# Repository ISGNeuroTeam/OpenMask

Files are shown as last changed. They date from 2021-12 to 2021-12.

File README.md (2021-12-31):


#


Наша команда разрабатывает open hardware open software проект уже более года.

### OpenMask= Умная маска + аналитическая Платформа + экспертиза моделей

**Описание проекта:** умная маска с 14 различными типами датчиков собирает биомедицинские данные с человека. Фиксирует и анализирует показатели работы сердечно-сосудистой, дыхательной и вегетативной нервной системы, а также данные о состоянии окружающей среды и типе физической активности в конкретный момент времени. Данные загружаются в открытую аналитическую Платформу, на их основе определяются потенциальные возможности организма и оценивается эффективность и безопасность тренировок.

**Цель проекта:**  создать бесплатную и открытую для самостоятельного повторения энтузиастами и стартапами IIoT  платформу, позволяющую собирать в открытую ОТ.Платформу  биомедицинские данные с активно действующего человека.

Эта инициатива позволяет нашему сообществу накапливать данные о работе человеческого организма в самых разных ситуациях и условиях, строить модели ML и сервисы решающие реальные проблемы людей.

**Все компоненты проекта полностью открыты и доступны для самостоятельных повторения и модификации**
**По ссылке на Github найдешь:**
+ Модели масок для 3D печати
+ Список необходимой электроники 
+ Инструкции по сборке 
+ Исходный код прошивки контроллера
+ Описание протокола взаимодействия с Аналитической платформой
+ Приложение для Android

**Придумай свой проект на основе OpenMask**
+ Сформулируй интересующую тебя актуальную проблему в области повышения качества жизни
+ Вместе с командой придумайте эксперимент
+ Соберите маску
+ Соберите данные с помощью маски и постройте модели
+ Или используйте загруженные в платформу данные для моделей
+ Сделайте стартап на основе ОТ.Платформы и маски

Конструкция устройства, и всё программное обеспечение полностью открыто и позволяет строить свои фитнес-гаджеты на его основе.

### Структура файлов проекта
> 1. 3D модели - файлы 3D моделей
> > 1. Главная часть (корпус) 
> > > 1. Главная часть - без отверстий
> > > 2. Главная часть - с отверстиями
> > 2. Крышки фильтров
> > > 1. Крышки - вид 1
> > > 2. Крышки - вид 2
> > > 3. Крышки - вид 3
> > 3. Кнопка
> > > 1. Кнопка без защелки
> > > 2. Кнопка с защелкой
> > 4. Датчик ФПГ
> > 6. Датчик внутренней среды
> 2. neuromask_esp8266 - исходники прошивки контроллера esp8266
> > 1. neuroMask_esp8266 - прошика контроллера без ШИЛДА
> > 2. neuroMask_esp8266_chield - прошика контроллера с ШИЛДОМ
> 3. Mobile App TrainerII - файл установки мобильного приложения ТренерИИ

### Вступление в Wellness Data Club — максимально короткий путь реализации твоих идей, МЕНЯЮЩИХ МИР К ЛУЧШЕМУ
[https://welldata.club](https://welldata.club)

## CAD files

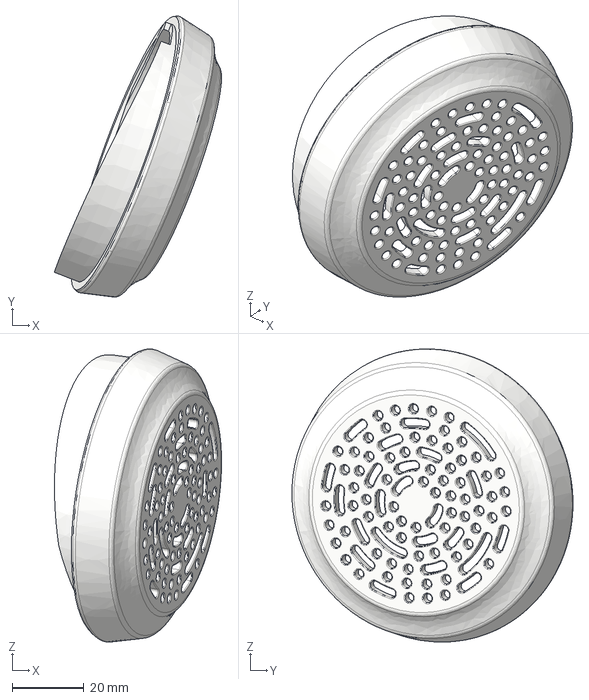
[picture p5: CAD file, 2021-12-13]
1. 3D модели/2. Крышки фильтров/1. Крышки - вид 1/крышка 1 левая.step
46.5 x 78.2 x 81.5 mm

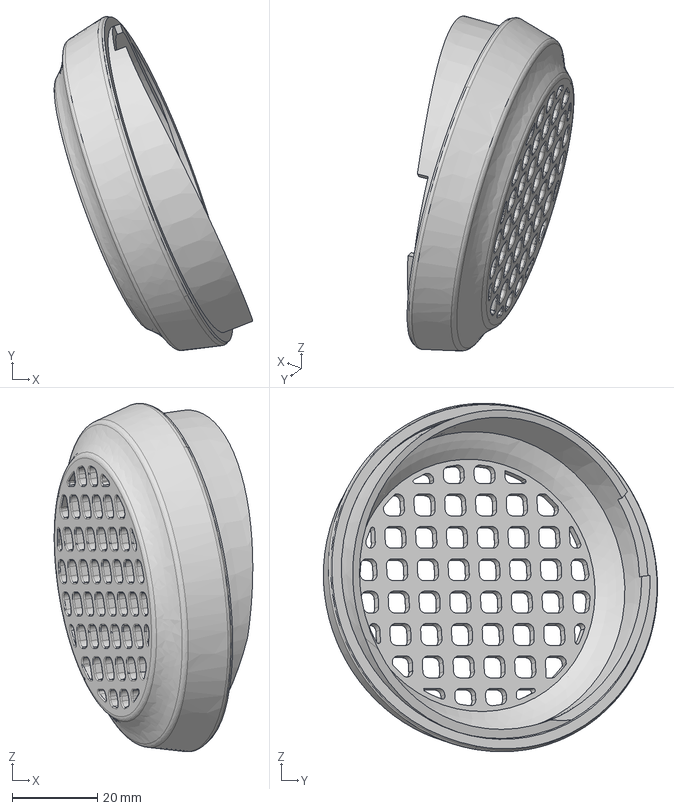
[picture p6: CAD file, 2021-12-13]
1. 3D модели/2. Крышки фильтров/3. Крышки - вид 3/крышка 3 правая.step
46.5 x 78.2 x 81.5 mm

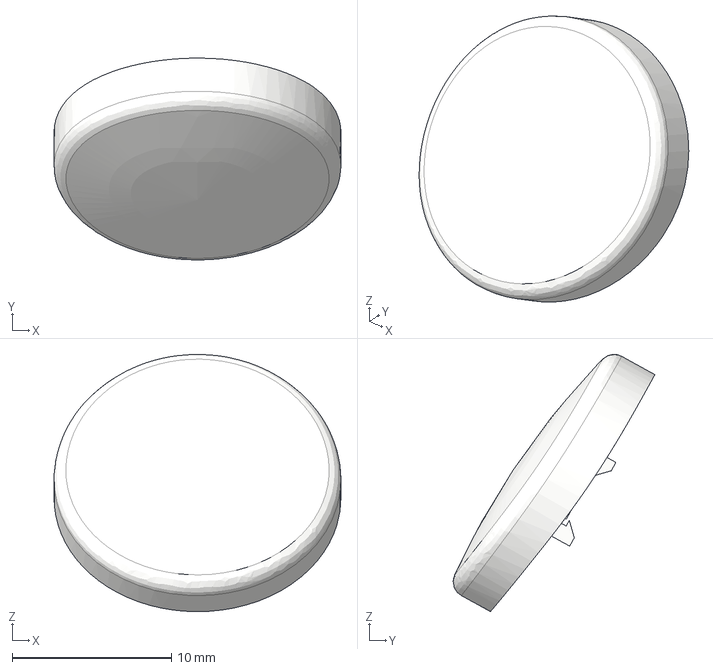
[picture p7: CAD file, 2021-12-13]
1. 3D модели/3. Кнопка/1. Кнопка без защелки/кнопка без защелок.step
18.0 x 12.7 x 16.1 mm

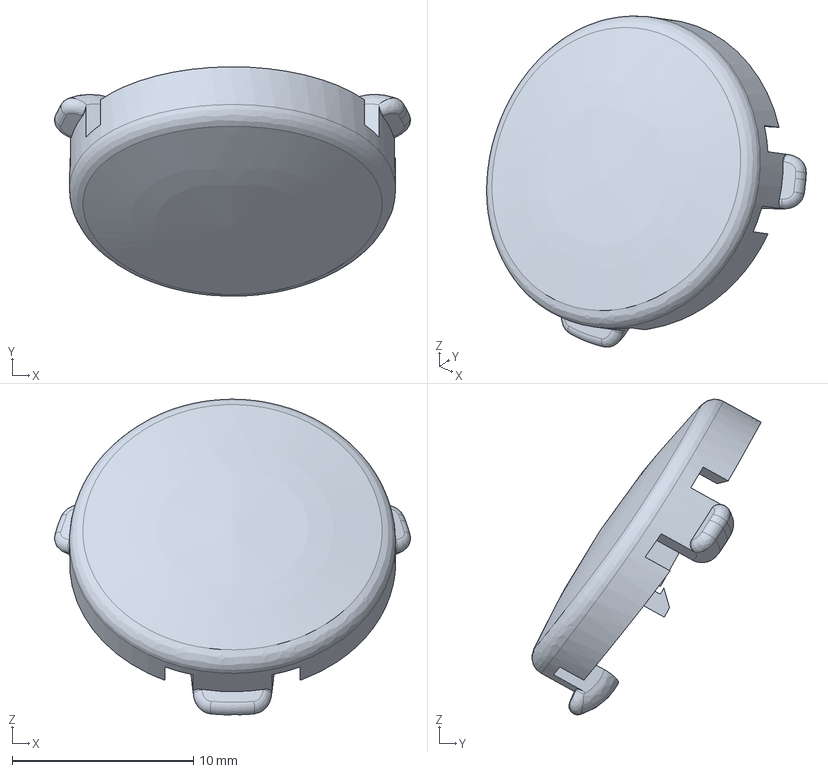
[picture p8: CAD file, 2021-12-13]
1. 3D модели/3. Кнопка/2. Кнопка с защелкой/кнопка с защелками.step
19.6 x 12.7 x 17.4 mm

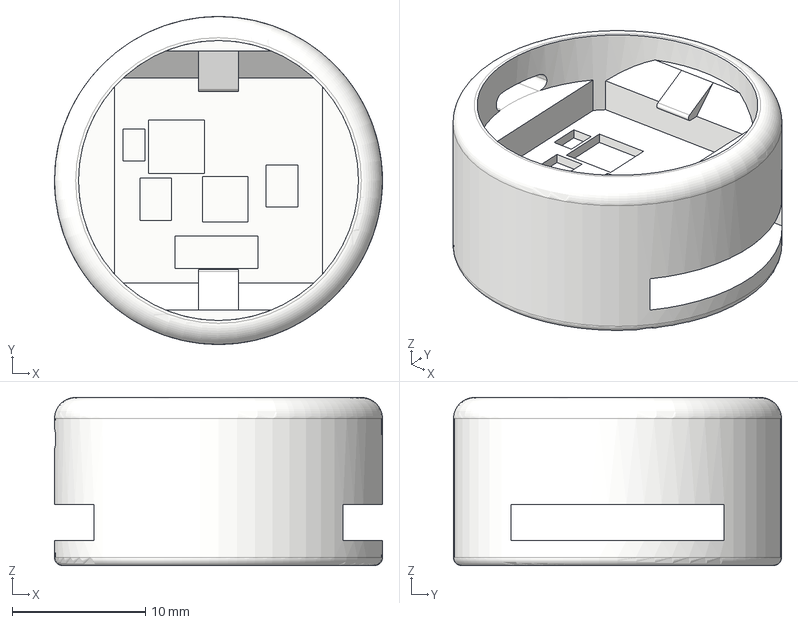
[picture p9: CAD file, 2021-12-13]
1. 3D модели/5. Датчик ФПГ/крепление фпг и иму.step
24.6 x 24.6 x 12.6 mm

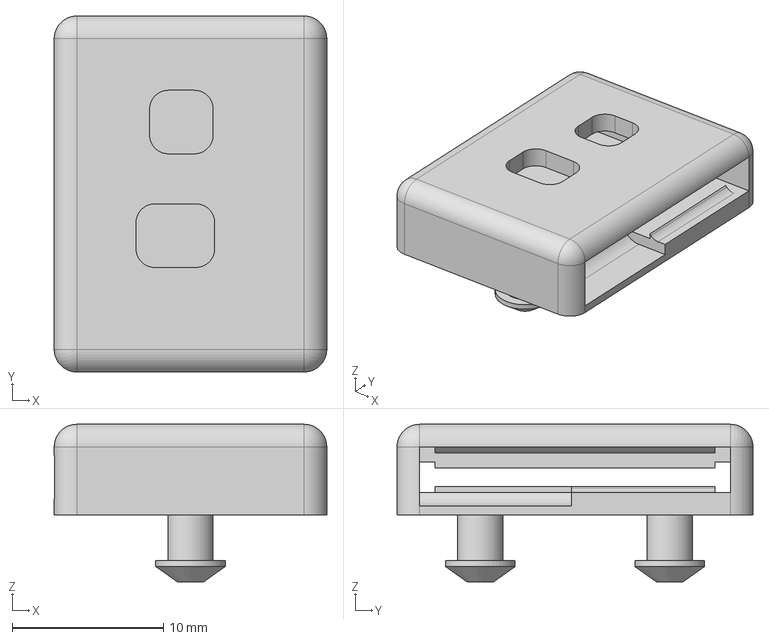
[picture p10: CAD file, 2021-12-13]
1. 3D модели/6. Датчик внутренней среды/крепление датчика внутренней среды.step
18.0 x 23.5 x 10.4 mm

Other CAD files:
1. 3D модели/2. Крышки фильтров/2. Крышки - вид 2/крышка 2 левая.step
1. 3D модели/2. Крышки фильтров/1. Крышки - вид 1/крышка 1 правая.step
1. 3D модели/2. Крышки фильтров/2. Крышки - вид 2/крышка 2 правая.step
1. 3D модели/2. Крышки фильтров/3. Крышки - вид 3/крышка 3 левая.step
1. 3D модели/3. Кнопка/1. Кнопка без защелки/кнопка без защелок.stl
1. 3D модели/3. Кнопка/2. Кнопка с защелкой/кнопка с защелками.stl
1. 3D модели/5. Датчик ФПГ/крепление фпг и иму.stl
1. 3D модели/6. Датчик внутренней среды/крепление датчика внутренней среды.stl

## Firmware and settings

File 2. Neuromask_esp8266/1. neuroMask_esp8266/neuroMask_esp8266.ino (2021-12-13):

#include <Wire.h>
#include <heartRate.h>
#include <MAX30105.h>
#include <Ticker.h>
#include <FaBo9Axis_MPU9250.h>
#include "EEPROM.h"
#include "DFRobot_CCS811.h"
#include "SparkFunBME280.h"
#include "Adafruit_HDC1000.h"
#include <Adafruit_NeoPixel.h>
#include <ESP8266WiFi.h>
#include <WiFiUdp.h>

#include <FIR.h>
FIR<int, 103> fir_lp;
FIR<int, 103> fir_lp_1;

#include <WiFiManager.h> // https://github.com/tzapu/WiFiManager

#define DEBUG false
//#define RESET_EEPROM false // uncomment to clear eeprom

//#define WEMOS

#ifdef WEMOS
#define BUTTONPIN 4
#define POWERPIN  5
#else
#define BUTTONPIN D4
#define POWERPIN  D5
// sensor keys
#endif

bool SLEEPMODE  = false;

// eeprom adress for save port host
#define IP_ADDRESS 0x00
#define PORT_ADDRESS 0x100
#define ASAP_ADDRESS 0x200


//ESP32AnalogRead adc; // adc conversion with calibration
#define VOLTAGE_BAT_PIN  A0
#define VOLTAGE_KOEF (100 + 210)/210  //(R1+R2)/R2
uint8_t BATPERCENTVALUE  = 0;  // save percent batery level

#define LEDS_COUNT  2
#define LEDS_PIN  12

Adafruit_NeoPixel pixels(LEDS_COUNT, LEDS_PIN, NEO_GRB + NEO_KHZ800);

#define CO2 0x10
#define O2 0x11
#define T_BODY 0x12
#define HUM 0x13
#define TVOC 0x14
#define PRESS 0x15
#define T_OUT 0x16
#define CARDIO 0x17
#define AX 0x18
#define AY 0x19
#define AZ 0x1A
#define GX 0x1B
#define GY 0x1C
#define GZ 0x1D
#define MX 0x1E
#define MY 0x1F
#define MZ 0x20
#define SPO2_RED 0x21
#define SPO2_IR 0x22
#define SPO2_GREEN 0x23
#define SPO2 0x24
#define ALT 0x25
#define HR 0x26
#define STEP 0x27
#define BAT_PERCENT 0x28
#define TVOCEXT 0x29
#define CO2EXT 0x2A
#define HUMEXT 0x2B



// received commands keys

#define STARTSENDDATA     0x50
#define STOPSENDDATA      0x51
#define SETFREQENCY       0x52
#define WITHPROCESSING    0x53
#define GETCONFIGSENSORS  0x54
#define GETMACADRESS      0x55





WiFiManager wm;
WiFiManagerParameter custom_address; // global param ( for non blocking w params )
WiFiManagerParameter custom_port; // global param ( for non blocking w params )
WiFiManagerParameter asAP; // global param ( for non blocking w params )


static const uint16_t startOfPacket =  0xAAF0;
static const uint16_t endOfPacket =  0xAAF1;

#define SENSCOUNT 22
#define DEFAULT_FREQ_HZ 100


Ticker sender;

Ticker batreader;

Ticker batShower;


volatile uint8_t sensReadCount = 0;
uint8_t sensorsActive[SENSCOUNT];

MAX30105 particleSensor; // sensor init

FaBo9Axis imu;  // Gyroscop Acellerometr

DFRobot_CCS811 CCS811;  // tvoc co2
DFRobot_CCS811 CCS811EXT(&Wire, 0x5B);  // tvoc co2 external sensor

BME280 bme;
BME280_SensorMeasurements measurements; // presure  & Humidity sens

Adafruit_HDC1000 hdc = Adafruit_HDC1000(); // external & Humidity sens

#define SEALEVELPRESSURE_HPA (1013.25) // Average sea-level pressure from wiki

typedef struct {
  uint8_t sensorId;   // id sensor
  float value;   // value
} structSensor;  // sensor struct

typedef struct {
  uint16_t dataLength;  // length data without start stop bits and self
  uint16_t timeStamp[2]; // timesatmp milliseconds from boot
  structSensor sensors[SENSCOUNT];  // array of sensors struct
} structPacket;  // struct of packet to send client

structPacket packet;

typedef struct {
  char modulName[10];  // name
  void (*functionRead)(void);  // coomand to read data
  bool enable;  // enable or disable reading
} structDevice; // struct of modul with sesors

void imuSensRead();
void practicleRead();
void readSensors();
void TvocCo2Read();
void TvocCo2ReadExt();
void HumiPressRead();
void HumiExtRead();
void VoltageRead();

structDevice devices[] = {  {"Imu", imuSensRead,   true},
  {"SpO2", practicleRead, true},
  {"CO2Tvoc", TvocCo2Read, true},
  {"ExCO2Tvoc", TvocCo2ReadExt, true},
  {"HumiPress", HumiPressRead, true},
  {"HumiExt", HumiExtRead, true},
  {"Voltage", VoltageRead, true}
};

// WiFi network name and password:
//const char * networkName = "";
//const char * networkPswd = "";

//IP address to send UDP data to:
// either use the ip address of the server or
// a network broadcast address

String udpAddress = "10.77.2.36";
int udpPort = 3333;

//Are we currently connected?
boolean connected = false;

//The udp library class
WiFiUDP udp;


float filter(float inputVal) {
  //implement the IIR filter
  //reference: The Scientist and Engineer's Guide to Digital Signal Processing By Steven W. Smith, Ph.D.
  //  http://www.dspguide.com/ch19/2.htm
  //This is a "single pole" filter.

  //x is the decay between adjacent samples. Choose any number between 0 and 1 (except 1).
  const float x = 0.86;
  static float outputVal = 0; //make it static so it's stored for the function to use again the next time it's called

  outputVal = outputVal * x + inputVal * (1 - x);
  return outputVal;
}

void writeStringToEEPROM(int addrOffset, String strToWrite)
{
  byte len = strToWrite.length();
  EEPROM.write(addrOffset, len);
  for (int i = 0; i < len; i++)
  {
    EEPROM.write(addrOffset + 1 + i, strToWrite[i]);
  }
}
String readStringFromEEPROM(int addrOffset)
{
  int newStrLen = EEPROM.read(addrOffset);
  char data[newStrLen + 1];
  for (int i = 0; i < newStrLen; i++)
  {
    data[i] = EEPROM.read(addrOffset + 1 + i);
    //Serial.print(data[i]);
  }
  data[newStrLen] = '\0'; // !!! NOTE !!! Remove the space between the slash "/" and "0" (I've added a space because otherwise there is a display bug)
  return String(data);
}

void disableDeviceByName(char * modulName)
{
  for (int i = 0; i < sizeof(devices) / sizeof(structDevice); i++ )
  {

    if (!memcmp(devices[i].modulName, modulName, strlen(modulName)))
    {
#if DEBUG
      Serial.println("Modul " + String(modulName) + " disable");
#endif
      devices[i].enable = false;
    }
  }
}

void timerSenderStart(int freq) {
#if DEBUG
  Serial.printf("Timer value is: %f\n", float(1) / freq);
#endif
  sender.attach(float(1) / freq, readSensors);
}

void timerSenderStop()
{
  sender.detach();
}

void timerSenderChangeFreq(int freq) // change frequncy timer
{
  timerSenderStop();
  timerSenderStart(freq);
}

void addDataSensToPacket(uint8_t sensorId, float value) // add sensor data to packet
{
  int sensIndex = (packet.dataLength /  (sizeof(uint8_t) + sizeof(float))) % SENSCOUNT;

  packet.sensors[sensIndex].sensorId = sensorId;
  packet.sensors[sensIndex].value = value;
  packet.dataLength += (sizeof(uint8_t) + sizeof(float));

}

void clearPacket()  // clear packet
{

  memset(&packet, 0, sizeof(packet));
}



bool VoltageInit()
{
  //adc.attach(VOLTAGE_BAT_PIN);
  return true;

}


bool practicleSensInit()
{
  // Initialize sensor
  if (particleSensor.begin(Wire, I2C_SPEED_FAST) == false) //Use default I2C port, 400kHz speed
  {
    Serial.println("MAX30105 was not found. Please check wiring/power. ");
    disableDeviceByName("SpO2");
    return false;
  }

  //Setup to sense up to 18 inches, max LED brightness
  byte ledBrightness = 0x2A; //Options: 0=Off to 255=50mA
  byte sampleAverage = 2; //Options: 1, 2, 4, 8, 16, 32
  byte ledMode = 3; //Options: 1 = Red only, 2 = Red + IR, 3 = Red + IR + Green
  int sampleRate = 3200; //Options:SENSCOUNT 50, 100, 200, 400, 800, 1000, 1600, 3200
  int pulseWidth = 69; //Options: 69, 118, 215, 411
  int adcRange = 4096; //Options: 2048, 4096, 8192, 16384

  particleSensor.setup(ledBrightness, sampleAverage, ledMode, sampleRate, pulseWidth, adcRange); //Configure sensor with these settings
  // default value (byte powerLevel = 0x1F, byte sampleAverage = 4, byte ledMode = 3, int sampleRate = 400, int pulseWidth = 411, int adcRange = 4096);
  return true;
}

bool imuSensInit()
{
  if (imu.begin()) {
    return true;
  }
  else {
    Serial.println("Imu was not found. Please check wiring/power.");
    disableDeviceByName("Imu");

    return false;
  }
}

bool TvocCo2Init()
{
  if (CCS811.begin() != 0) {
    Serial.println("failed to init chip, please check if the chip connection is fine");
    disableDeviceByName("CO2Tvoc");
    return false;

  }
  else
  {
    return true;
  }
}

bool TvocCo2InitExt()
{
  if (CCS811EXT.begin() != 0) {
    Serial.println("failed to init ccs811 external chip, please check if the chip connection is fine");
    disableDeviceByName("ExCO2Tvoc");
    return false;
  }
  else
  {
    return true;
  }
}

bool HumiExtSensInit()
{
  if (!hdc.begin()) {
    Serial.println("Couldn't find sensor HDC100x , check wiring!");
    disableDeviceByName("HumiExt");
    return false;
  }
  return true;
}


bool pressureHumiSensInit()
{
  bme.setI2CAddress(0x77);
  if (bme.beginI2C() == false) {
    Serial.println("Could not find a valid BME285 sensor, check wiring!");
    disableDeviceByName("HumiPress");
    return false;
  }
  bme.setStandbyTime(6);
  bme.readAllMeasurements(&measurements);
  //bme.setReferencePressure(101750);
  delay(10);
  return true;
}

void readBatPercent()
{
  float batVoltage = analogRead(A0);

  float max_adc = 730;
  float min_adc = 530;
  //Serial.println(batVoltage);


  //BATPERCENTVALUE = batVoltage;

  if (batVoltage > max_adc)
  {
    BATPERCENTVALUE = 100;
  }
  else if (batVoltage < min_adc)
  {
    BATPERCENTVALUE = 0;
  }
  else
  {
    BATPERCENTVALUE  = map(batVoltage, min_adc, max_adc, 0, 100);
  }

}

void VoltageRead()
{
  static uint32_t lastTimeSend = millis();
  if (millis() - lastTimeSend > 1000) // send each seconds
  {
    addDataSensToPacket(BAT_PERCENT, BATPERCENTVALUE);
    sensReadCount += 1;
    lastTimeSend = millis();
  }

}

void HumiExtRead()
{
  float hum, temp;
  if (hdc.readHumidityAndTemp(&hum, &temp))
  {
    addDataSensToPacket(HUMEXT, hum);
    sensReadCount += 1;
  }


}

void HumiPressRead()
{
  if (!bme.isMeasuring())
  {
    bme.readAllMeasurements(&measurements);

    float alt =  ((float) - 44330.77) * (pow(((float)measurements.pressure / (float)bme.getReferencePressure()), 0.190263) - (float)1);
    Serial.println(measurements.pressure);

    addDataSensToPacket(T_OUT, measurements.temperature);
    addDataSensToPacket(PRESS, measurements.pressure);
    addDataSensToPacket(HUM, measurements.humidity);
    addDataSensToPacket(ALT, alt);
    sensReadCount += 4;
  }


}



void TvocCo2Read() {
  if (CCS811.checkDataReady() == true) {
    float co2 = CCS811.getCO2PPM();
    float ppm = CCS811.getTVOCPPB();
    addDataSensToPacket(TVOC, ppm);
    addDataSensToPacket(CO2, co2);
    sensReadCount += 2;

  } else {


    return;
  }

}

void TvocCo2ReadExt() {

  if (CCS811EXT.checkDataReady() == true) {
    float co2 = CCS811EXT.getCO2PPM();
    float ppm = CCS811EXT.getTVOCPPB();
    addDataSensToPacket(TVOCEXT, ppm);
    addDataSensToPacket(CO2EXT, co2);
    sensReadCount += 2;

  } else {
    return;
  }

}

void imuSensRead()
{
  float ax, ay, az;
  float gx, gy, gz;
  float mx, my, mz;
  float temp;
  sensReadCount += 10;

  imu.readAccelXYZ(&ax, &ay, &az);
  imu.readGyroXYZ(&gx, &gy, &gz);
  imu.readMagnetXYZ(&mx, &my, &mz);
  imu.readTemperature(&temp);
  addDataSensToPacket(AX, ax);
  addDataSensToPacket(AY, ay);
  addDataSensToPacket(AZ, az);
  addDataSensToPacket(GX, gx);
  addDataSensToPacket(GY, gy);
  addDataSensToPacket(GZ, gz);
  addDataSensToPacket(MX, mx);
  addDataSensToPacket(MY, my);
  addDataSensToPacket(MZ, mz);
  addDataSensToPacket(T_BODY, temp);
#if DEBUG
  //Serial.println(ax);
#endif
#if DEBUG
  //Serial.println(gx);
#endif
#if DEBUG
  //Serial.println(temp);
#endif
}



float getBPM(float value)
{
  static long lastBeat = 0; //Time at which the last beat occurred

  if (checkForBeat(value) == true)
  {
    //We sensed a beat!
    long delta = millis() - lastBeat;
    lastBeat = millis();

    float beatsPerMinute = 60 / (delta / 1000.0);

    return filter(beatsPerMinute);

  }
  return -1;
}

void practicleRead() {
  static int counter = 0;
  particleSensor.check();
  if (!particleSensor.available())
  {

#if DEBUG
    Serial.println("no data");
#endif
    return;
  }
  float red, ir, green;

  red = particleSensor.getFIFORed();
  ir = particleSensor.getFIFOIR();
  green = particleSensor.getFIFOGreen();
  sensReadCount += 3;
  particleSensor.nextSample();
  addDataSensToPacket(SPO2_RED, red);
  addDataSensToPacket(SPO2_IR, ir);
  addDataSensToPacket(SPO2_GREEN, green);


  float clean_ir = fir_lp.processReading(ir);
  float clean_red = fir_lp_1.processReading(red);
  if (ir < 50000)
    return;
  float beatsPerMinute = getBPM(clean_ir);

  if (beatsPerMinute > 30 && beatsPerMinute < 220 )
  {

    addDataSensToPacket(HR, beatsPerMinute);
    sensReadCount++;

  }

}
uint8_t activeSensorCounter()
{
  uint8_t counter = 0;

  for (uint8_t i = 0; i < SENSCOUNT; i++)
  {
    if (sensorsActive[i] != 0)
    {
      counter++;
    }
  }
  return counter;
}
uint8_t scanModules()
{
  uint8_t counter = 0; // sensors counter

  if (imuSensInit())
  {
    sensorsActive[counter++] =  AX;
    sensorsActive[counter++] =  AY;
    sensorsActive[counter++] =  AZ;
    sensorsActive[counter++] =  GX;
    sensorsActive[counter++] =  GY;
    sensorsActive[counter++] =  GZ;
    sensorsActive[counter++] =  MX;
    sensorsActive[counter++] =  MY;
    sensorsActive[counter++] =  MZ;
    sensorsActive[counter++] =  T_BODY;
  }
  if (practicleSensInit())
  {
    sensorsActive[counter++] = SPO2_RED;
    sensorsActive[counter++] = SPO2_IR;
    sensorsActive[counter++] = SPO2_GREEN;
  }

  if (TvocCo2Init())
  {
    sensorsActive[counter++] = TVOC;
    sensorsActive[counter++] = CO2;
  }
  if (TvocCo2InitExt())
  {
    sensorsActive[counter++] = TVOCEXT;
    sensorsActive[counter++] = CO2EXT;
  }


  if (pressureHumiSensInit())
  {
    sensorsActive[counter++] = PRESS;
    sensorsActive[counter++] = HUM;
    sensorsActive[counter++] = T_OUT;
    sensorsActive[counter++] = ALT;
  }

  if (HumiExtSensInit())
  {
    sensorsActive[counter++] = HUMEXT;
  }
  if (VoltageInit())
  {
    sensorsActive[counter++] = BAT_PERCENT;
  }

  return counter;
}

String getParam(String name) {
  //read parameter from server, for customhmtl input
  String value;
  if (wm.server->hasArg(name)) {
    value = wm.server->arg(name);
  }
  return value;
}

void saveParamCallback() {

  //#if DEBUG
  Serial.println("[CALLBACK] saveParamCallback fired");
  Serial.println("PARAM hostip = " + getParam("hostip"));
  Serial.println("PARAM hostport = " + getParam("hostport"));
  Serial.println("PARAM asAP = " + getParam("asAP"));
  //#endif

  writeStringToEEPROM(IP_ADDRESS, getParam("hostip"));
  writeStringToEEPROM(PORT_ADDRESS, getParam("hostport"));
  writeStringToEEPROM(ASAP_ADDRESS, getParam("asAP"));
  EEPROM.commit();
}



//wifi event handler
void WiFiEvent(WiFiEvent_t event) {
  switch (event) {
    case WIFI_EVENT_SOFTAPMODE_STACONNECTED:
      {
#if DEBUG
        Serial.print("Client connected! IP address: ???");
#endif
        if (!connected)
          udp.begin(udpPort);
        connected = true;
        //send_sensors();
      }
      break;

    case WIFI_EVENT_STAMODE_GOT_IP:
      {
        //When connected set
#if DEBUG
        Serial.print("WiFi connected! IP address: ");
#endif
#if DEBUG
        Serial.println(WiFi.localIP());
#endif
        //initializes the UDP state
        //This initializes the transfer buffer
        udp.begin(udpPort);
        connected = true;
        send_sensors();
      }
      break;
    case WIFI_EVENT_STAMODE_DISCONNECTED:
      {
#if DEBUG
        Serial.println("WiFi lost connection");
#endif
        connected = false;
        break;
      }
    default: break;
  }
}

void startConfigAPServer()
{
  WiFi.mode(WIFI_STA); // explicitly set mode, esp defaults to STA+AP
  //WiFi.setTxPower(WIFI_POWER_MINUS_1dBm);

  WiFi.onEvent(WiFiEvent); //register event handler

  int customFieldLength = 40;
  const char* custom_text_str = "<label for='hostip'>Host IP</label><input type='text' name='hostip'><br>";
  const char* custom_port_str = "<br/><label for='hostport'>Host port</label><input type='number' name='hostport'><br>";
  const char* custom_asAP = "<br/><label for='asAP'>As Access Point</label><input type='checkbox' id='asAP' name='asAP'><br>";
  new (&custom_address) WiFiManagerParameter(custom_text_str); // custom html input
  new (&custom_port) WiFiManagerParameter(custom_port_str);
  new (&asAP) WiFiManagerParameter(custom_asAP);

  wm.addParameter(&custom_address);
  wm.addParameter(&custom_port);
  wm.addParameter(&asAP);
  wm.setSaveParamsCallback(saveParamCallback);

  std::vector<const char *> menu = {"wifi", "info", "param", "sep", "restart", "exit"};
  wm.setMenu(menu);

  // set dark theme
  wm.setClass("invert");

  //wm.setConfigPortalTimeout(90);
  //wm.resetSettings();
  bool res;
  res = wm.autoConnect(); // auto generated AP name from chipid
  //res = wm.autoConnect("AutoConnectAP"); // anonymous ap
  //res = wm.autoConnect("AutoConnectAP", "password"); // password protected ap

  if (!res) {
    Serial.println("Failed to connect");
    ESP.restart();

  }
  else {
    //if you get here you have connected to the WiFi
    Serial.println("NeuroMask connected");

  }
}

void responseCommand(uint8_t * packet, int len)
{
  uint8_t commandId =  packet[2];
  float param;
  *((uint8_t *)(&param) + 3) = packet[3];
  *((uint8_t *)(&param) + 2) = packet[4];
  *((uint8_t *)(&param) + 1) = packet[5];
  *((uint8_t*)(&param) + 0)  = packet[6];

  switch (commandId)
  {
    case GETCONFIGSENSORS:
      send_sensors();
#if DEBUG
      Serial.print("Get config sensors command received");
#endif
      break;

    case STARTSENDDATA:
      timerSenderStart(DEFAULT_FREQ_HZ);
#if DEBUG
      Serial.print("Start sensors data sending command received");
#endif
      break;

    case STOPSENDDATA:
      timerSenderStop();
#if DEBUG
      Serial.print("Stop sensors data sending command received");
#endif
      break;

    case SETFREQENCY:
      timerSenderStart(param);
#if DEBUG
      Serial.printf("Set frequency data sending command received, freq=%f", param);
#endif
      break;

    case GETMACADRESS:
      sendMacAddress();
#if DEBUG
      Serial.print("Get mac address command received");
#endif
      break;


  }

}

void readIncomingUdp()
{
  if (connected)
  {

    int packetSize = udp.parsePacket();

    if (packetSize)
    {
      uint8_t incomingPacket[packetSize];  // buffer for incoming packets
      // receive incoming UDP packets
#if DEBUG
      Serial.printf("Received %d bytes from %s, port %d\n", packetSize, udp.remoteIP().toString().c_str(), udp.remotePort());
#endif
      int len = udp.read(incomingPacket, packetSize);
      udpAddress = udp.remoteIP().toString().c_str();
      udpPort = udp.remotePort();
      if (len == 9)
      {
#if DEBUG
        Serial.printf("Received command %02x and value %02x%02x%02x%02x\n", incomingPacket[2], incomingPacket[3], incomingPacket[4], incomingPacket[5], incomingPacket[6]);
#endif
        responseCommand(incomingPacket, len);
      }


#if DEBUG
      Serial.printf("UDP packet contents: %s\n", incomingPacket);
#endif
    }
  }
}

void offLedStatus()
{
  pixels.clear();
  pixels.show();
}

void showLedStatus()
{


  if (BATPERCENTVALUE > 50)
  {
    pixels.setPixelColor(0, pixels.Color(0, 200, 0));
    pixels.setPixelColor(1, pixels.Color(0, (BATPERCENTVALUE - 50) * 2, 0));
  }
  else if (BATPERCENTVALUE > 10)
  {
    pixels.setPixelColor(0, pixels.Color(0, BATPERCENTVALUE * 2, 0));
    pixels.setPixelColor(1, pixels.Color(0, 0, 0));
  }
  else
  {
    pixels.setPixelColor(0, pixels.Color(BATPERCENTVALUE, 0, 0));
    pixels.setPixelColor(1, pixels.Color(BATPERCENTVALUE, 0, 0));
  }
  pixels.show();
  batShower.once(5, offLedStatus);
}


void lowPassFilterInit()
{
  int coef_lp[103] = { -67, -257, -146, -240, -276, -327, -368, -403, -426, -436, -431, -408, -369,
                       -313, -242, -159, -68, 26, 119, 204, 276, 331, 362, 368, 346, 296, 220, 121,
                       5, -121, -250, -372, -477, -557, -602, -605, -560, -464, -315, -116, 129, 414,
                       728, 1061, 1399, 1730, 2038, 2311, 2537, 2707, 2811, 2847, 2811, 2707, 2537, 2311,
                       2038, 1730, 1399, 1061, 728, 414, 129, -116, -315, -464, -560, -605, -602, -557,
                       -477, -372, -250, -121, 5, 121, 220, 296, 346, 368, 362, 331, 276, 204, 119, 26,
                       -68, -159, -242, -313, -369, -408, -431, -436, -426, -403, -368, -327, -276, -240,
                       -146, -257, -67
                     };
  fir_lp.setFilterCoeffs(coef_lp);
  fir_lp_1.setFilterCoeffs(coef_lp);

}

void setup() {
  pinMode(POWERPIN, OUTPUT);
  digitalWrite(POWERPIN, HIGH);

  // Initilize hardware serial:
  Serial.begin(115200);
#if DEBUG
  Serial.println("starting");
#endif
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
void loop() {
  String inputString;
  while (Serial.available()) {

    // get the new byte:
    char inChar = (char)Serial.read();
    // add it to the inputString:
    inputString += inChar;
    // if the incoming character is a newline, set a flag so the main loop can
    // do something about it:
    if (inputString == "restart") {
      Serial.print("restarting....");
      ESP.restart();

      break;
    }
    if (inputString == "reset") {
      Serial.print("hard reset....");
      wm.resetSettings();
      writeStringToEEPROM(ASAP_ADDRESS, "off");
      EEPROM.commit();
      ESP.restart();

      break;
    }
    delayMicroseconds(100);

  }
  readIncomingUdp();
  readButtonState();

}

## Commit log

2021-12-31 add mobile
    Добавлено мобильное приложение
    [кнопка с защелками.step, кнопка с защелками.stl, крепление датчика внутренней среды.step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]
2022-01-04 новая версия приложения
